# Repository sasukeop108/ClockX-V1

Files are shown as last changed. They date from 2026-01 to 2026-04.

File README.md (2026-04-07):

# ClockX-V1

This is a clock which can display time, Date etc, alarms can be set ,has games and has 4 inbuilt buttons to control them.
I decided to make this because i wake up from sleep, I cannot se the time clearly because the clock is far away from my
bed and im feeling lazy to move near the clock and see the time , So i designed ClockX which has my most favourite and usefull things at one place. First, I thought of soldering them in a zeropcb but as I was curious in learning cad and pcb designing I made a pcb and enclosure for it.

It is powered by a wemos d1 mini for proccessing all data and has 0.96 inch i2c oled display for displaying all the datas.
It has a menu with  4 options which are NTP clock, Alarm, Setting, and game. It has 1000 MaH which would power them  for some hours.
It derives time 
using the NTP protocol and inbuilt WiFi of wemos d1 mini. It has a chrome dino game in the game menu.
# Finished build
WhatsApp Image 2026-03-31 at 14 14 21
# Demo url
https://www.youtube.com/shorts/HJBQToIP37M
# cad with pcb
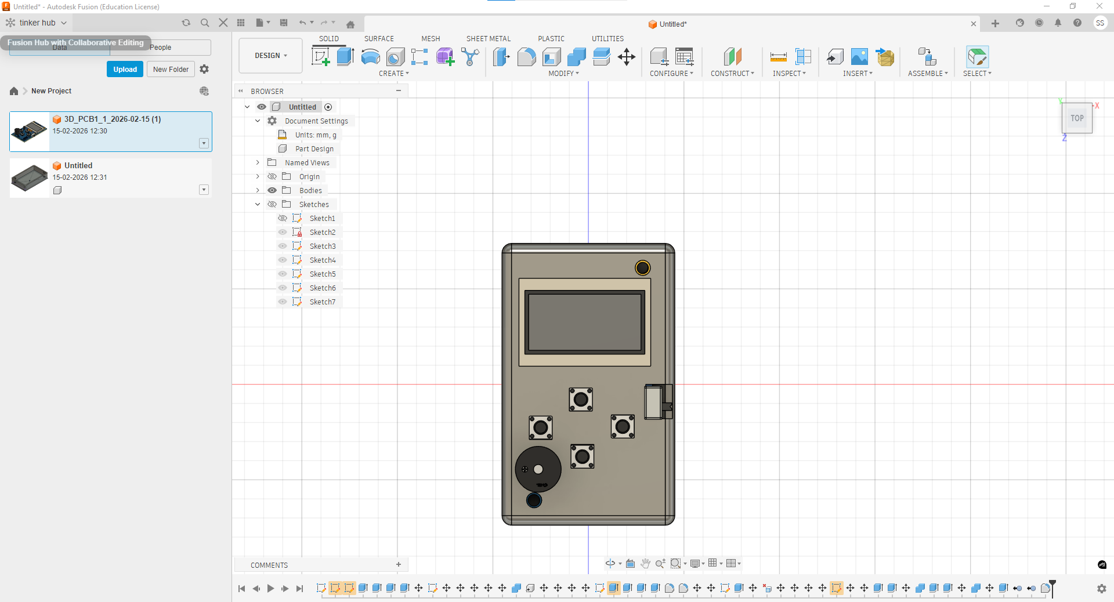
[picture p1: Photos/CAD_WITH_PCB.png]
Cad with pcb

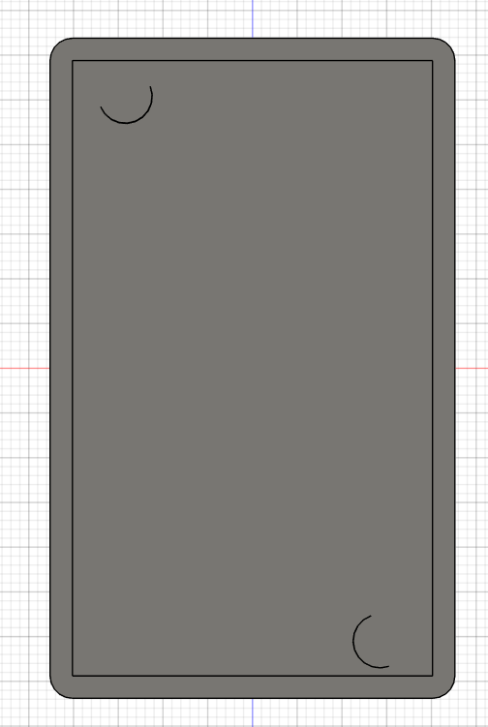
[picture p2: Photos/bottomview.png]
Schematic1


# 2D PCB & Schematic
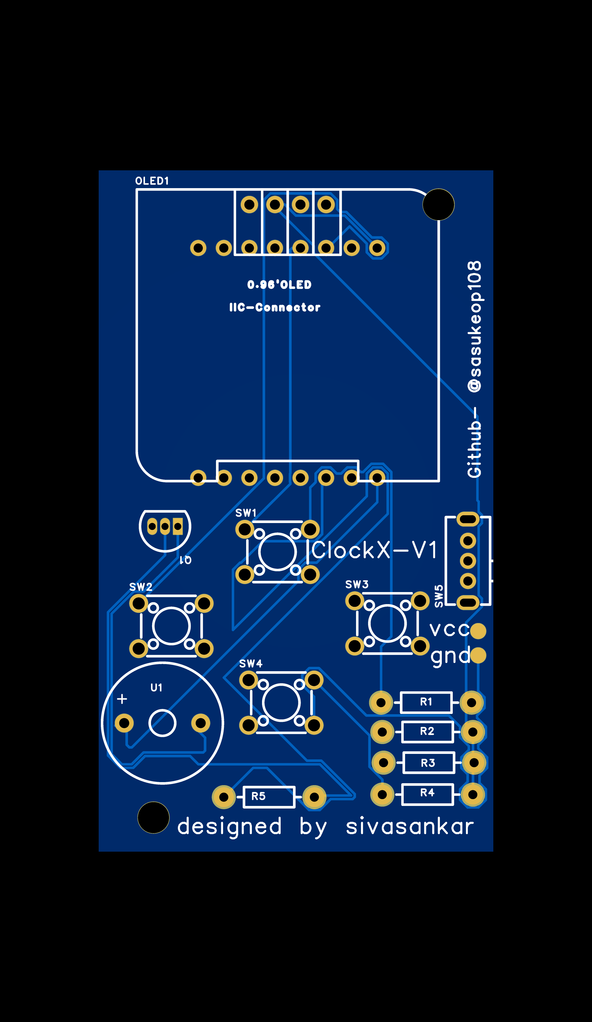
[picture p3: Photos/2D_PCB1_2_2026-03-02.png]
2d pcb

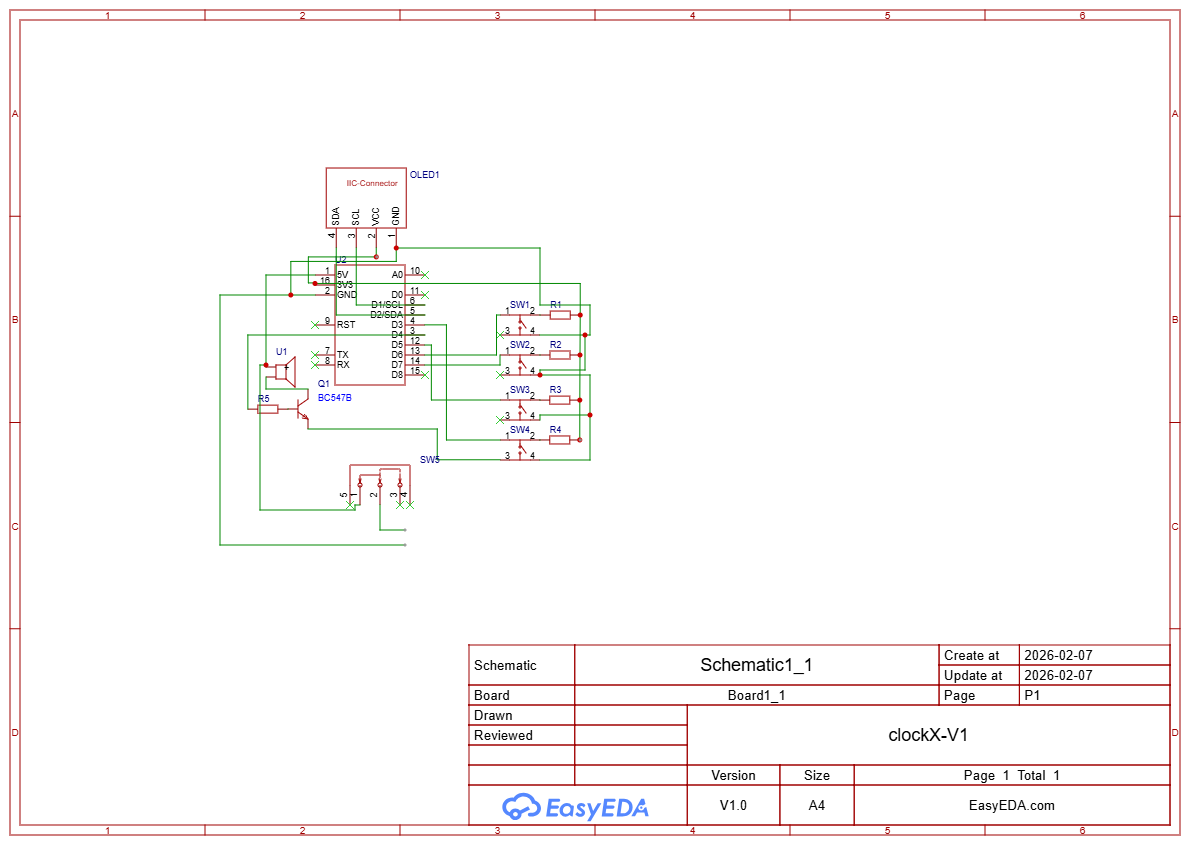
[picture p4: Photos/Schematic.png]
Schematic

# Circuit Diagram
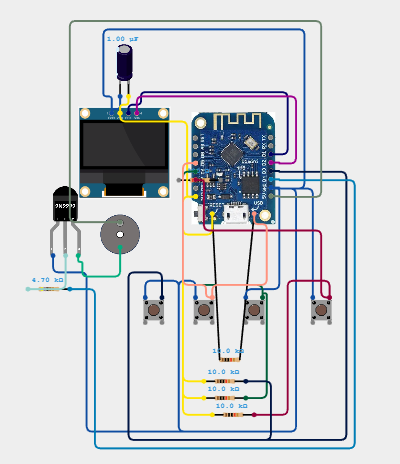
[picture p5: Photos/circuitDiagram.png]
Circuit Diagram

# BOM
# Bill of Materials

| Item | Description | Qty | Unit Price (INR) | Total (INR) | Unit Price (USD)* | Total (USD)* | Link |
| :--- | :--- | :--- | :--- | :--- | :--- | :--- | :--- |
| Microcontroller | Wemos D1 Mini | 1 | ₹699.00 | ₹699.00 | $8.42 | $8.42 | [makerbazar.in](https://makerbazar.in/products/wemos-d1-mini-iot-esp8266-based-development-board?variant=48251175600368) |
| DISPLAY | 128x64 I2C OLED Display | 1 | ₹189.00 | ₹189.00 | $2.28 | $2.28 | [makerbazar.in](https://makerbazar.in/products/0-96-inch-128x64-oled-display-module) |
| Boost Module | Step-up Converter | 1 | ~~₹65.00~~ | **Self Sourced** | ~~$0.78~~ | **Self Sourced** | **Self Sourced** |
| Buzzer | Hdp1206 Active Buzzer | 1 | ₹19.00 | ₹19.00 | $0.23 | $0.23 | [makerbazar.in](https://makerbazar.in/products/b12-hdp1206-mini-active-buzzer) |
| Button | 6x6mm Push Button | 1 | ₹20.00 | ₹20.00 | $0.24 | $0.24 | [makerbazar.in](https://makerbazar.in/products/small-push-button-switch?variant=44840000880880) |
| Battery | 800mAh LiPo Battery | 1 | ₹150.00 | ₹150.00 | $1.81 | $1.81 | [quartzcomponents.com](https://quartzcomponents.com/products/3-7v-800mah-li-po-rechargeable-battery) |
| Charger | TP4056 Charger Module | 1 | ₹16.00 | ₹16.00 | $0.19 | $0.19 | [makerbazar.in](https://makerbazar.in/products/tp4056-1a-li-ion-lithium-battery-charging-module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) |
| Resistor | 10kΩ THT Resistor (Pack of 10) | 1 | ₹5.00 | ₹5.00 | $0.06 | $0.06 | [makerbazar.in](https://makerbazar.in/products/carbon-film-resistor-dip-1-4-watt-resistance-through-hole-1k-to-99kohm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) |
| Power Switch | Slide Switch (SPDT) | 2 | ₹8.00 | ₹16.00 | $0.10 | $0.19 | [makerbazar.in](https://makerbazar.in/products/right-angle-3-pin-2-position-spdt-1p2t-pcb-panel-mini-slide-switch-l-shape-bent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) |
| Capacitor | 100µF 16V Capacitor (Pack of 10) | 1 | ₹12.00 | ₹12.00 | $0.14 | $0.14 | [makerbazar.in](https://makerbazar.in/products/electrolytic-capacitor-through-hole?variant=48721342562544) |
| Header | Female Berg Strip (40-pin) | 1 | ~~₹8.50~~ | **Self Sourced** | ~~$0.10~~ | **Self Sourced** | **Self Sourced** |
| Nut | M3*12mm nut (Pack of 10) | 1 | ₹42.00 | ₹42.00 | $0.51 | $0.51 | [quartzcomponents.com](https://quartzcomponents.com/products/m3-x-10mm-hex-allen-socket-head-ss202-screwpack-of-10) |
| Heat Insert | M3x12mm Brass Heat Set Insert Nut (10 Pcs) | 2 | ₹42.00 | ₹84.00 | $0.51 | $1.02 | [quartzcomponents.com](https://quartzcomponents.com/products/m3x12mm-brass-heat-set-threaded-round-insert-nut-10-pcs) |
| Heatshrink | Black Heatshrink (1m) | 1 | ₹7.00 | ₹7.00 | $0.08 | $0.08 | [makerbazar.in](https://makerbazar.in/products/heat-shrink?variant=44960740475120) |
| **Subtotal (Purchased Components)** | | | | **₹1259.00** | | **$15.17** | |
| **Maker Bazaar Delivery** | | | | **+₹60.00** | | **+$0.72** | |
| **Quartz Components Delivery** | | | | **+₹50.00** | | **+$0.60** | |
| **Quartz Components Tax** | | | | **+₹58.68** | | **+$0.71** | |
| **PCB Grant** | PCB Manufacturing Grant | | | **+728.61** | | **+$8** | |
| **3D Print Grant** |Shipping Grant | | | **+₹273.23** | | **+$3.00** | |
| **GRAND TOTAL** | | | | **₹2429** | | **$26.80** | |

*\*Note: USD conversions are approximate and based on an exchange rate of 1 USD = 83 INR. Actual rates may vary at the time when you see. It is approximately 27 dollar according to today's exchange rate.*

## Summary

- **Maker Bazar Purchased Items:** 9 items totaling **₹983.00** (Wemos + Display + Buzzer + Button + Charger + Resistor + Switch + Capacitor + Heatshrink)
- **Quartz Components Items:** Battery + Nut + 2×Heat Insert = **₹276.00**
- **Self Sourced Items:** Boost Module (₹65) + Header (₹8.50) = **₹73.50**
- **Delivery & Tax:** Maker Bazaar Delivery (₹60) + Quartz Delivery (₹50) + Quartz Tax (₹58.68) = **₹168.68**
- **Grants:** PCB Grant (₹728.61) + 3D Print Grant (₹273.23) = **₹1002**
- **Grand Total:** **2429 INR** (approximately **$27 USD**)

## Self Sourced Items (Not Purchased)
- Boost Module (Step-up Converter) - ₹65.00
- Header (Female Berg Strip 40-pin) - ₹8.50

# Key Features
* Game high scores are saved in EEPROM

* Alarms will still continue even when the game is being used

* All the alarm's are saved in EEPROM

* Live and accurate time with no mistake

* The use of a specific button can be changed by coding

  # Libraries Required

  * Wire.h
  * u8g2lib.h
  * ESP8266WiFi.h
  * EEPROM.h
  * NTPClient.h
  * WiFiUDP.h

 **Reference and inspiration**

 https://youtu.be/3gI2dTkNN_A?si=NC1nUjIlxpC8zosO
    
**Project url**- https://blueprint.hackclub.com/projects/9123

**Installation**

First, Solder the wemos d1 mini after thar Solder other Components and flash the firmware.Now Solder the battery wires in Vcc and gnd pad. Next, Insert the heart inserts into case usin a soldering iron and keep that pcb in place,keep the lod above it and tighten the screws.Finally, You're ready to go with ClockX!

**Estimated battery life**

4.5 to 6 hours~

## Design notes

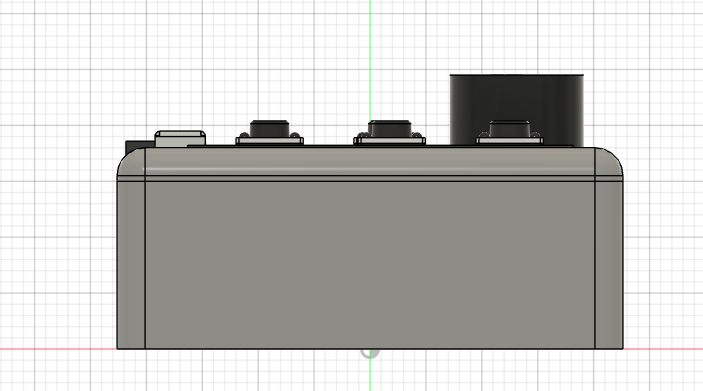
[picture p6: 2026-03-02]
Photos/backview.png

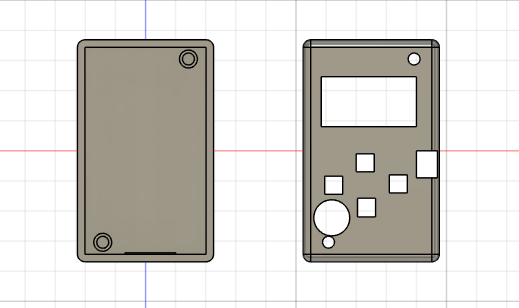
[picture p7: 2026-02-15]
Photos/CAD_WITHOUT_PCB.png

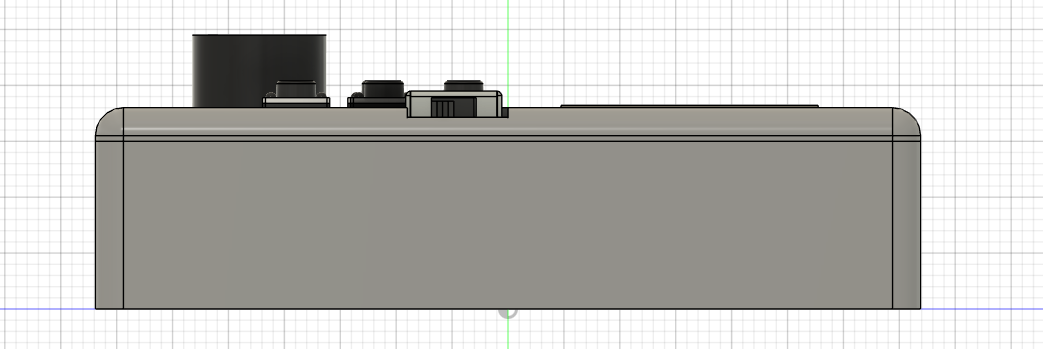
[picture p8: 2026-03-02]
Photos/rightview.png

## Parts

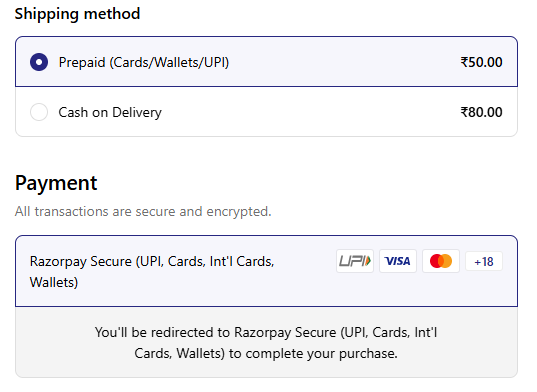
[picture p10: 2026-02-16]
BOM/QuartzComponents_Delivery.png

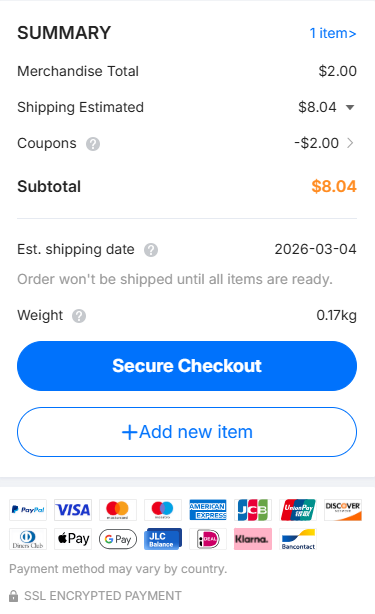
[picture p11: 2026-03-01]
BOM/jlcpcb6.png

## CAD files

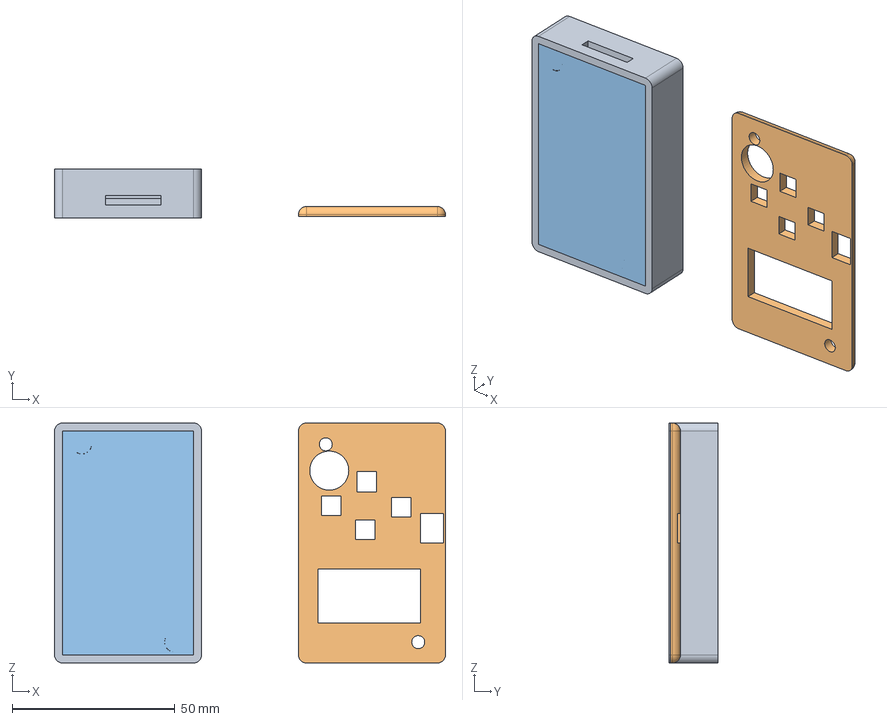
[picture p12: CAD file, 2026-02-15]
CAD/ClockX-V1_NO_PCB (1).step
120.2 x 15.0 x 73.8 mm

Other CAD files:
CAD/CaseBottom.f3d
CAD/TopCase.f3d

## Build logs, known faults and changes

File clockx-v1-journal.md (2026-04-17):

<!--
  This journal is auto generated by Hack Club Blueprint.
-->

# 1/7/2026 6 PM - Designed OLED UI  

_Time spent: 1.0h_  

**DAY** 1

Today, I designed a good user interface for my OLED display using lopaka. It turned out  very well. I also include options to use Clock and Game seperately. It took me 45 mins but UI was worth for spending the time.

# 1/7/2026 9 PM - Designed circuit diagram  

_Time spent: 1.0h_  

**DAY 1** circuitDiagram
Today, I spent 1 hour and to choose components and complete my circuit diagram. I added all the components needed for the project and connected them. Finally i checked all the wiring and ensured that there were no mistakes in the wiring part.

# 1/8/2026 - Started coding for the proect  

_Time spent: 1.3h_  

**DAY 2**

Today, I started coding for my project's NTP clock part. Learnt basics ofu8g2, NTPClient and wrote this code. I had many syntax errors in my code. After compiling, Found 6 syntax errors which i fixed immediately.

My code had some declaration and software errors too which i also fixed and compiled again. This time, There were no errors and NTP CLOCK part was good to go. I completed 1 part out of the 3 parts of my project which are NTP clock, Game and ALARM.

**TIME SPENT** : Around 1 hour & 30 mins  

# 1/9/2026 - Completed coding the project  

_Time spent: 3.4h_  

**DAY 3**

Today, I modified the code which i wrote yesterday. The code which i wrote yesterday was too 
basic, So today i modified all the basic code to advanced which was pretty cool at first. After completing the code, I realized that the button management was too complex.

Due to the complexity of button handling i added a setting in menu which will display all the button handling. Also, The previous code only had clock, But today i added all the parts (games,settings,alarm). Like always had many errors which i fixed.

**time spent**: 3.45 Hour.  

# 1/11/2026 - Created BOM and changed circuit diagram  

_Time spent: 2.0h_  

**DAY 4**

Today, There were several changes in my project. I changed the micro controller from esp8266 to wemos d1 mini because of its very small size. Because oh this i also was forced to create a new circuit diagram. i did it.

Also, I created the BOM of my project using excel. This might be the final journal of my project because my project is in final phase which is prototyping.

**TIME SPENT**: 2 hours  

# 2/15/2026 - Drew schematic, Routed pcb and created a 3d enclosure   

_Time spent: 3.1h_  

CAD_WITH_PCB

**CAD_WITHOUT_PCB**
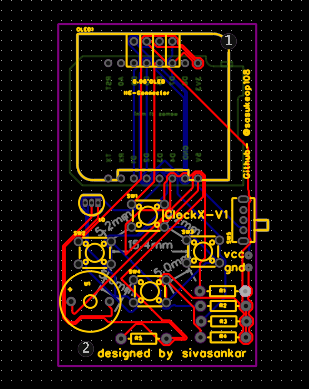
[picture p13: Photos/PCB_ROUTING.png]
PCB_ROUTING
Schematic
**DAY 5**

Today, I started by creating a schematic for my pcb in easy eda and routed the pcb again and again until I felt it was fine. It took very long perfecting it and was satisfied of the routing the pcb finally.

After that, I started creating a enclosure for the pcb. It was also same like routing pcb. It took long to perfect it but not very much comparing to the pcb routing. Finally completed 3 works and I was satisfied very much of my work.

**TIME SPENT- 3 HOUR 10 MINUTES**  

# 2/24/2026 - Update in prices  

_Time spent: 0.1h_  

Screenshot_20260224_163838_Chrome

Today when I checked the prices of pcbs in jlcpcb, The prices have been reduced due to end of chinese new year,so now the Grant I require has been changed to 29.34 dollar

# 3/1/2026 - Change in the Grant needed  

_Time spent: 0.1h_  

Screenshot_20260301_140226_Chrome AS the shipping cost for 3d Print is bargained and reduced to 3 dollar from 6 dollar, The Grant which I want has been updated to 24 dollars. SO I Have updated BOM  

# 3/14/2026 - Uploaded Firmware and tested  

_Time spent: 3.0h_  

Today, I received all of the components needed for my project except the pcb. So i uploaded the firmware to the wemos d1 mini. After that i used the pcb schematic to form a circuit using breadboard and breadboard wires. There were some problems too after fixing them it worked well and i have tested it with the lipo battery too.WhatsApp Image 2026-03-14 at 22.12.18
WhatsApp Image 2026-03-14 at 22.12.19

# 3/18/2026 - Soldered all parts in pcb  

_Time spent: 3.0h_  

Today, i received my pcb from jlcpcb so i started soldering all the components onto the pcb. First, It was working fine but after i soldered the buzzer,Transistor and its resistor the esp suddenly crashed. I was panicked for a minute because the esp didnt reset and screen didnt work. I debugged for approx 1 hour and i finally found out that the buzzer was pulling the boot pin high during boot. After i removed those components it started working fine.WhatsApp Image 2026-03-18 at 21.09.08

# 3/31/2026 - Completed the project  

_Time spent: 2.2h_  

WhatsApp Image 2026-03-31 at 14.14.21
WhatsApp Image 2026-03-31 at 14.14.22
Today, I got my 3d parts so i inserted the heat inserts. After that i soldered tp4056 and boost module, secured them in place. I also done some other small changes in my code for improving the project. Finally now it is completed and this might be my last journal.

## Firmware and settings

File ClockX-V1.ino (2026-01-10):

//by Sivasankar github repository: https://github.com/sasukeop108/ClockX-V1

#include <U8g2lib.h>
#include <NTPClient.h>
#include <WiFiUdp.h>
#include <ESP8266WiFi.h>
#include <Wire.h>
#include <EEPROM.h>

//BUTTON PIN ASSIGNMENTS
#define b1 12  // D6 - GPIO12 (Menu navigation) Add 10KΩ resistor to 3.3V!
#define b2 13  // D7 - GPIO13 (Select/Jump) Add 10KΩ resistor to 3.3V!
#define b3 14  // D5 - GPIO14 (Increase/Restart) Add 10KΩ resistor to 3.3V!
#define b4 0   // D3 - GPIO0 (Decrease/Back)  Add 10KΩ resistor to 3.3V!

// Buzzer Pin
#define BUZZER_PIN 2  // D4 - GPIO2 connect this pin to base of 2n222a transistor with a 1k resistor,connect emitter with gnd and connect buzzer gnd to collector and positive of buzzer to 5v

int sen = 1; // Start at Clock (1=Clock, 2=Game, 3=Alarm, 4=Settings)

// OLED Display
U8G2_SSD1306_128X64_NONAME_F_HW_I2C u8g2(U8G2_R0, U8X8_PIN_NONE);

// NTP Client
WiFiUDP ntpUDP;
NTPClient timeClient(ntpUDP, "pool.ntp.org", 19800);

// Icons
static const unsigned char image_calendar_bits[] U8X8_PROGMEM = {0x90,0x04,0x6e,0x3b,0xff,0x7f,0xff,0x7f,0x01,0x40,0x61,0x5b,0x61,0x5b,0x01,0x40,0x6d,0x5b,0x6d,0x5b,0x01,0x40,0x6d,0x43,0x6d,0x43,0x01,0x40,0xfe,0x3f,0x00,0x00};
static const unsigned char image_clock_alarm_bits[] U8X8_PROGMEM = {0x9e,0x3c,0xcd,0x59,0xb7,0x76,0x0b,0x68,0x05,0x50,0x82,0x20,0x82,0x20,0x81,0x40,0x83,0x60,0x41,0x40,0x22,0x20,0x12,0x20,0x04,0x10,0x08,0x08,0xb4,0x16,0xc2,0x21};
static const unsigned char image_wifi_full_bits[] U8X8_PROGMEM = {0x80,0x0f,0x00,0xe0,0x3f,0x00,0x78,0xf0,0x00,0x9c,0xcf,0x01,0xee,0xbf,0x03,0xf7,0x78,0x07,0x3a,0xe7,0x02,0xdc,0xdf,0x01,0xe8,0xb8,0x00,0x70,0x77,0x00,0xa0,0x2f,0x00,0xc0,0x1d,0x00,0x80,0x0a,0x00,0x00,0x07,0x00,0x00,0x02,0x00,0x00,0x00,0x00};
static const unsigned char image_settings_bits[] U8X8_PROGMEM = {
  0x00,0x00,0x0e,0x00,0x1f,0x00,0x3b,0x80,0x71,0xc0,0xe0,0xe0,0xc0,0x70,0x80,0x38,
  0x00,0x1c,0x00,0x0e,0x00,0x07,0x80,0x03,0xc0,0x01,0xe0,0x00,0x70,0x00,0x38,0x00,
  0x1c,0x00,0x0e,0x00,0x07,0x80,0x03,0xc0,0x01,0xe0,0x00,0x70,0x00,0x38,0x00,0x1c,
  0x00,0x0e,0x00,0x07,0x80,0x03,0xc0,0x01,0xe0,0x00,0x70,0x00,0x38,0x00,0x00,0x00
};

// BUZZER FUNCTIONS
void playTone(int frequency, int duration) {
  if (frequency == 0) {
    noTone(BUZZER_PIN);
    return;
  }
  tone(BUZZER_PIN, frequency, duration);
}

void playPulsingAlarm() {
  static unsigned long lastToneTime = 0;
  static int pulseState = 0;
  unsigned long currentTime = millis();
  
  if (currentTime - lastToneTime > 100) {
    switch(pulseState) {
      case 0: playTone(1000, 80); break;
      case 1: playTone(1200, 80); break;
      case 2: playTone(1400, 80); break;
      case 3: playTone(0, 0); break;
    }
    pulseState = (pulseState + 1) % 4;
    lastToneTime = currentTime;
  }
}

void playJumpSound() { playTone(800, 50); delay(10); playTone(600, 40); }
void playGameOverSound() { playTone(300, 200); delay(100); playTone(200, 300); delay(150); playTone(150, 400); }
void playButtonClick() { playTone(500, 30); }
void playAlarmSetSound() { playTone(800, 100); delay(50); playTone(1000, 100); }
void stopAllSounds() { noTone(BUZZER_PIN); }

// EEPROM
#define EEPROM_SIZE 512
#define HIGH_SCORE_ADDR 0

struct Alarm {
  byte hour;
  byte minute;
  bool enabled;
};

#define MAX_ALARMS 3
Alarm alarms[MAX_ALARMS];

// GAME VARIABLES
#define GROUND_Y 54
#define GRAVITY 0.5
#define JUMP_FORCE -9.0
#define INITIAL_SPEED 3

// Dino Sprites
static const unsigned char dino_run1[] U8X8_PROGMEM = {
  0x00,0x00,0x00,0x00,0x00,0x00,0x00,0x00,0x00,0x00,0x00,0x00,0x00,0x00,0x00,0x00,
  0x00,0x00,0x00,0x00,0x00,0x00,0x00,0x00,0x00,0x00,0x03,0xe0,0x03,0xf0,0x07,0xf0,
  0x07,0xf0,0x07,0xf0,0x07,0xf0,0x07,0xe0,0x07,0xf0,0x07,0xf0,0x07,0xf8,0x0f,0xf8,
  0x0f,0xf8,0x0f,0xf0,0x07,0xf0,0x07,0xf0,0x03,0xe0,0x00,0x00,0x00,0x00,0x00,0x00
};

static const unsigned char cactus_small[] U8X8_PROGMEM = {
  0x00,0x00,0x01,0x80,0x01,0x80,0x01,0x80,0x01,0x80,0x01,0x80,0x01,0x80,0x01,0x80,
  0x01,0x80,0x01,0x80,0x01,0x80,0x01,0x80,0x01,0x80,0x01,0x80,0x01,0x80,0x01,0x80,
  0x01,0x80,0x01,0x80,0x01,0x80,0x01,0x80,0x01,0x80,0x01,0x80,0x01,0x80,0x01,0x80,
  0x01,0x80,0x01,0x80,0x01,0x80,0x01,0x80,0x01,0x80,0x01,0x80,0x01,0x80,0x00,0x00
};

struct Dino {
  float x = 10;
  float y = GROUND_Y - 16;
  float velocity = 0;
  bool jumping = false;
  int frame = 0;
} dino;

struct Obstacle {
  float x;
  bool active = false;
};

Obstacle obstacles[2];
bool gameOver = false;
unsigned long score = 0;
unsigned long highScore = 0;
float gameSpeed = INITIAL_SPEED;

// ALARM STATE
int alarmMenuState = 0;
int currentAlarm = 0;
int editingField = 0;
bool alarmTriggered = false;

//WIFI 
const char* ssid = "Sivasankarjio 5g";
const char* password = "siva2012";

String WeekDays[7] = {"Sun", "Mon", "Tue", "Wed", "Thu", "Fri", "Sat"};
String Months[13] = {"", "Jan", "Feb", "Mar", "Apr", "May", "Jun", "Jul", "Aug","Sep", "Oct", "Nov", "Dec"};

//SETUP 
void setup() {
  Serial.begin(115200);
  
  // Initialize buttons
  pinMode(b1, INPUT);  // D6
  pinMode(b2, INPUT);  // D7
  pinMode(b3, INPUT);  // D5
  pinMode(b4, INPUT);  // D3 
  
  // Initialize buzzer
  pinMode(BUZZER_PIN, OUTPUT);
  digitalWrite(BUZZER_PIN, LOW);
  
  u8g2.begin();
  u8g2.clearBuffer();
  u8g2.setFont(u8g2_font_t0_18b_tr);
  u8g2.drawStr(5, 28, "CONNECTING TO");
  u8g2.drawStr(46, 44, "WiFi");
  u8g2.sendBuffer();
  
  // Initialize EEPROM
  EEPROM.begin(EEPROM_SIZE);
  loadHighScore();
  loadAlarms();
  
  WiFi.begin(ssid, password);
  while (WiFi.status() != WL_CONNECTED) {
    delay(500);
  }
  
  timeClient.begin();
  
  // Startup sound
  playButtonClick();
  delay(200);
  playButtonClick();
}

// EEPROM FUNCTIONS
void loadHighScore() {
  EEPROM.get(HIGH_SCORE_ADDR, highScore);
  if (highScore > 100000) highScore = 0;
}

void saveHighScore() {
  EEPROM.put(HIGH_SCORE_ADDR, highScore);
  EEPROM.commit();
}

void loadAlarms() {
  for(int i = 0; i < MAX_ALARMS; i++) {
    int addr = 10 + (i * sizeof(Alarm));
    EEPROM.get(addr, alarms[i]);
  }
}

void saveAlarms() {
  for(int i = 0; i < MAX_ALARMS; i++) {
    int addr = 10 + (i * sizeof(Alarm));
    EEPROM.put(addr, alarms[i]);
  }
  EEPROM.commit();
  playAlarmSetSound();
}

// MAIN LOOP
void loop() {
  // Show main menu (NOW WITH 4 OPTIONS)
  u8g2.clearBuffer();
  u8g2.setFont(u8g2_font_t0_12b_tr);
  u8g2.drawStr(22, 10, "WiFi NTP CLOCK");
  u8g2.drawStr(52, 25, "GAME");
  u8g2.drawStr(49, 40, "ALARM");
  u8g2.drawStr(44, 55, "SETTINGS");
  
  // Highlight current selection
  if (sen == 1) u8g2.drawFrame(19, 1, 92, 16);      // Clock
  else if (sen == 2) u8g2.drawFrame(47, 18, 33, 14); // Game
  else if (sen == 3) u8g2.drawFrame(43, 33, 40, 14); // Alarm
  else if (sen == 4) u8g2.drawFrame(39, 48, 55, 14); // Settings
  
  u8g2.sendBuffer();
  
  // Button handling
  if (digitalRead(b1) == LOW) {  // D6 - Menu navigation
    delay(200);
    playButtonClick();
    sen++;
    if (sen > 4) sen = 1;
  }
  
  if (digitalRead(b2) == LOW) {  // D7 - Select
    delay(200);
    playButtonClick();
    
    if (sen == 1) {
      showClock();
    } 
    else if (sen == 2) {
      playDinoGame();
    }
    else if (sen == 3) {
      showAlarmSystem();
    }
    else if (sen == 4) {
      showSettings();
    }
  }
  
  delay(50);
}

// CLOCK FUNCTION 
void showClock() {
  unsigned long lastUpdate = 0;
  
  while (digitalRead(b1) == HIGH) {
    if(millis() - lastUpdate > 1000) {
      timeClient.update();
      time_t epochTime = timeClient.getEpochTime();
      struct tm *ptm = localtime(&epochTime);
      
      int mday = ptm->tm_mday;
      int mon = ptm->tm_mon + 1;
      int year = ptm->tm_year + 1900;
      String date = (mday < 10 ? "0" : "") + String(mday) + " " + Months[mon] + " " + String(year % 100);
      
      int hour24 = timeClient.getHours();
      int mins = timeClient.getMinutes();
      int secs = timeClient.getSeconds();
      String period = (hour24 < 12) ? "AM" : "PM";
      int h12 = (hour24 % 12 == 0) ? 12 : hour24 % 12;
      String timeDisplay = (h12 < 10 ? "0" : "") + String(h12) + ":" + (mins < 10 ? "0" : "") + String(mins);
      
      checkAlarmTrigger();
      
      u8g2.clearBuffer();
      
      // Header
      u8g2.setFont(u8g2_font_4x6_tr);
      u8g2.drawStr(1, 6, "WiFi NTP CLOCK");
      u8g2.drawLine(2, 7, 127, 7);
      
      // Time
      u8g2.setFont(u8g2_font_t0_22b_tr);
      u8g2.drawStr(28, 42, timeDisplay.c_str());
      
      // Seconds
      u8g2.setFont(u8g2_font_t0_14b_tr);
      u8g2.setCursor(85, 42);
      u8g2.print(secs < 10 ? "0" : "");
      u8g2.print(secs);
      
      // Day and AM/PM
      u8g2.setFont(u8g2_font_t0_11b_tr);
      u8g2.drawStr(88, 23, WeekDays[timeClient.getDay()].c_str());
      u8g2.drawStr(22, 22, period.c_str());
      
      // Date
      u8g2.setFont(u8g2_font_t0_11b_tr);
      u8g2.setCursor(0, 56);
      u8g2.print(date);
      
      // Icons
      u8g2.drawXBMP(108, 12, 19, 16, image_wifi_full_bits);
      u8g2.drawXBMP(3, 10, 15, 16, image_clock_alarm_bits);
      u8g2.drawXBMP(104, 45, 15, 16, image_calendar_bits);
      
      u8g2.sendBuffer();
      lastUpdate = millis();
    }
    
    if(alarmTriggered) {
      showAlarmTriggered();
    }
    
    delay(10);
  }
  delay(200);
}

void checkAlarmTrigger() {
  if(alarmTriggered) return;
  
  int currentHour = timeClient.getHours();
  int currentMinute = timeClient.getMinutes();
  
  for(int i = 0; i < MAX_ALARMS; i++) {
    if(alarms[i].enabled && 
       alarms[i].hour == currentHour && 
       alarms[i].minute == currentMinute) {
      alarmTriggered = true;
      break;
    }
  }
}

void showAlarmTriggered() {
  static bool blink = false;
  static unsigned long lastBlink = 0;
  
  u8g2.clearBuffer();
  
  if(millis() - lastBlink > 300) {
    blink = !blink;
    lastBlink = millis();
  }
  
  if(blink) {
    u8g2.setDrawColor(0);
    u8g2.drawBox(0, 0, 128, 64);
    u8g2.setDrawColor(1);
  }
  
  u8g2.setFont(u8g2_font_timR24_tr);
  u8g2.drawStr(20, 35, "ALARM!");
  
  u8g2.setFont(u8g2_font_t0_11b_tr);
  u8g2.drawStr(40, 55, "Press b2 to stop");
  
  u8g2.sendBuffer();
  
  playPulsingAlarm();
  
  if(digitalRead(b2) == LOW) {
    alarmTriggered = false;
    stopAllSounds();
    delay(200);
  }
}

//DINO GAME
void playDinoGame() {
  resetGame();
  
  u8g2.clearBuffer();
  u8g2.setFont(u8g2_font_t0_16b_tr);
  u8g2.drawStr(35, 20, "DINO");
  u8g2.drawStr(25, 40, "PRESS B2");
  u8g2.drawStr(20, 55, "TO JUMP");
  u8g2.sendBuffer();
  delay(1500);
  
  unsigned long lastFrame = 0;
  unsigned long lastObstacle = millis();
  
  while(digitalRead(b1) == HIGH && !gameOver) {
    unsigned long now = millis();
    
    if(now - lastFrame >= 16) {
      updateGame();
      drawGame();
      lastFrame = now;
    }
    
    if(digitalRead(b2) == LOW) {
      if(!dino.jumping) {
        dino.velocity = JUMP_FORCE;
        dino.jumping = true;
        playJumpSound();
      }
      delay(100);
    }
    
    if(gameOver && digitalRead(b3) == LOW) {
      resetGame();
      playButtonClick();
      delay(200);
    }
    
    if(now - lastObstacle > random(1000, 2500)) {
      spawnObstacle();
      lastObstacle = now;
    }
    
    delay(1);
  }
  
  if(gameOver) {
    showGameOver();
    delay(2000);
  }
}

void updateGame() {
  if(dino.jumping) {
    dino.y += dino.velocity;
    dino.velocity += GRAVITY;
    
    if(dino.y >= GROUND_Y - 16) {
      dino.y = GROUND_Y - 16;
      dino.jumping = false;
      dino.velocity = 0;
    }
  }
  
  dino.frame = (dino.frame + 1) % 20;
  
  for(int i = 0; i < 2; i++) {
    if(obstacles[i].active) {
      obstacles[i].x -= gameSpeed;
      
      if(obstacles[i].x < -10) {
        obstacles[i].active = false;
        score += 1;
      }
    }
  }
  
  for(int i = 0; i < 2; i++) {
    if(obstacles[i].active) {
      if(dino.x + 16 > obstacles[i].x &&
         dino.x < obstacles[i].x + 8 &&
         dino.y + 16 > GROUND_Y - 16) {
        gameOver = true;
        playGameOverSound();
        if(score > highScore) {
          highScore = score;
          saveHighScore();
        }
        return;
      }
    }
  }
}

void drawGame() {
  u8g2.clearBuffer();
  
  u8g2.drawLine(0, GROUND_Y, 128, GROUND_Y);
  
  if(dino.frame < 10) {
    u8g2.drawXBMP(dino.x, dino.y, 16, 16, dino_run1);
  } else {
    u8g2.drawXBMP(dino.x, dino.y, 16, 16, dino_run1);
  }
  
  for(int i = 0; i < 2; i++) {
    if(obstacles[i].active) {
      u8g2.drawXBMP(obstacles[i].x, GROUND_Y - 16, 8, 16, cactus_small);
    }
  }
  
  char scoreStr[20];
  u8g2.setFont(u8g2_font_5x7_tr);
  sprintf(scoreStr, "SCORE: %lu", score);
  u8g2.drawStr(80, 10, scoreStr);
  
  sprintf(scoreStr, "HIGH: %lu", highScore);
  u8g2.drawStr(80, 20, scoreStr);
  
  u8g2.sendBuffer();
}

void spawnObstacle() {
  for(int i = 0; i < 2; i++) {
    if(!obstacles[i].active) {
      obstacles[i].x = 128;
      obstacles[i].active = true;
      break;
    }
  }
}

void resetGame() {
  dino.x = 10;
  dino.y = GROUND_Y - 16;
  dino.velocity = 0;
  dino.jumping = false;
  dino.frame = 0;
  
  for(int i = 0; i < 2; i++) {
    obstacles[i].active = false;
  }
  
  score = 0;
  gameSpeed = INITIAL_SPEED;
  gameOver = false;
}

void showGameOver() {
  u8g2.clearBuffer();
  
  u8g2.setFont(u8g2_font_t0_16b_tr);
  u8g2.drawStr(30, 20, "GAME OVER");
  
  u8g2.setFont(u8g2_font_t0_12b_tr);
  char scoreStr[30];
  sprintf(scoreStr, "Score: %lu", score);
  u8g2.drawStr(40, 35, scoreStr);
  
  sprintf(scoreStr, "High: %lu", highScore);
  u8g2.drawStr(40, 50, scoreStr);
  
  u8g2.drawStr(10, 63, "b3=Restart  b1=Exit");
  
  u8g2.sendBuffer();
}

//ALARM SYSTEM
void showAlarmSystem() {
  alarmMenuState = 0;
  currentAlarm = 0;
  
  while(digitalRead(b1) == HIGH) {
    
    if(alarmMenuState == 0) {
      u8g2.clearBuffer();
      u8g2.setFont(u8g2_font_t0_16b_tr);
      u8g2.drawStr(40, 15, "ALARMS");
      
      u8g2.setFont(u8g2_font_6x10_tr);
      
      for(int i = 0; i < MAX_ALARMS; i++) {
        char alarmStr[20];
        sprintf(alarmStr, "%d: %02d:%02d %s", 
                i+1, 
                alarms[i].hour, 
                alarms[i].minute,
                alarms[i].enabled ? "ON" : "OFF");
        
        int yPos = 30 + (i * 12);
        
        if(i == currentAlarm) {
          u8g2.drawBox(0, yPos-10, 128, 12);
          u8g2.setDrawColor(0);
        }
        
        u8g2.drawStr(5, yPos, alarmStr);
        
        if(i == currentAlarm) {
          u8g2.setDrawColor(1);
        }
      }
      
      u8g2.drawStr(5, 58, "b2:Edit  b3:Next  b4:Prev");
      
      u8g2.sendBuffer();
      
      if(digitalRead(b2) == LOW) {
        delay(200);
        playButtonClick();
        alarmMenuState = 1;
        editingField = 0;
      }
      
      if(digitalRead(b3) == LOW) {
        delay(200);
        playButtonClick();
        currentAlarm = (currentAlarm + 1) % MAX_ALARMS;
      }
      
      if(digitalRead(b4) == LOW) {
        delay(200);
        playButtonClick();
        currentAlarm = (currentAlarm - 1 + MAX_ALARMS) % MAX_ALARMS;
      }
    }
    else {
      static bool blink = false;
      static unsigned long lastBlink = 0;
      
      if(millis() - lastBlink > 500) {
        blink = !blink;
        lastBlink = millis();
      }
      
      u8g2.clearBuffer();
      u8g2.setFont(u8g2_font_t0_16b_tr);
      char title[20];
      sprintf(title, "ALARM %d", currentAlarm + 1);
      u8g2.drawStr(30, 15, title);
      
      u8g2.setFont(u8g2_font_timR24_tr);
      char timeStr[6];
      sprintf(timeStr, "%02d:%02d", alarms[currentAlarm].hour, alarms[currentAlarm].minute);
      u8g2.drawStr(26, 45, timeStr);
      
      if(blink) {
        if(editingField == 0) {
          u8g2.drawBox(26, 46, 40, 3);
        } else if(editingField == 1) {
          u8g2.drawBox(70, 46, 40, 3);
        }
      }
      
      u8g2.setFont(u8g2_font_6x10_tr);
      char statusStr[20];
      sprintf(statusStr, "Status: %s", alarms[currentAlarm].enabled ? "ENABLED" : "DISABLED");
      
      if(editingField == 2 && blink) {
        u8g2.drawBox(45, 48, 60, 10);
        u8g2.setDrawColor(0);
      }
      u8g2.drawStr(45, 58, statusStr);
      u8g2.setDrawColor(1);
      
      u8g2.setFont(u8g2_font_4x6_tr);
      u8g2.drawStr(5, 63, "b3/b4:Adjust  b2:Save");
      
      u8g2.sendBuffer();
      
      if(digitalRead(b2) == LOW) {
        delay(200);
        playButtonClick();
        saveAlarms();
        alarmMenuState = 0;
      }
      
      if(digitalRead(b3) == LOW) {
        delay(200);
        playButtonClick();
        adjustAlarmValue(1);
      }
      
      if(digitalRead(b4) == LOW) {
        delay(200);
        playButtonClick();
        adjustAlarmValue(-1);
      }
    }
    
    delay(10);
  }
  
  delay(200);
}

void adjustAlarmValue(int delta) {
  switch(editingField) {
    case 0: alarms[currentAlarm].hour = (alarms[currentAlarm].hour + delta + 24) % 24; break;
    case 1: alarms[currentAlarm].minute = (alarms[currentAlarm].minute + delta + 60) % 60; break;
    case 2: alarms[currentAlarm].enabled = !alarms[currentAlarm].enabled; break;
  }
  editingField = (editingField + 1) % 3;
}

// SETTINGS/HELP MENU 
void showSettings() {

  int settingsPage = 0;
  
  while(digitalRead(b1) == HIGH) {
    
    if(settingsPage == 0) {
      // BUTTON GUIDE PAGE - Optimized layout
      u8g2.clearBuffer();
      
      u8g2.setFont(u8g2_font_t0_16b_tr);
      u8g2.drawStr(30, 12, "BUTTON GUIDE");
      u8g2.drawLine(2, 15, 126, 15);
      
      // Use 4x6 font for everything
      u8g2.setFont(u8g2_font_4x6_tr);
      
      // Row 1
      u8g2.drawStr(5, 25, "b1(D6): Menu Nav/Exit");
      
      // Row 2
      u8g2.drawStr(5, 33, "b2(D7): Select/Jump");
      
      // Row 3
      u8g2.drawStr(5, 41, "b3(D5): Increase/Next");
      
      // Row 4
      u8g2.drawStr(5, 49, "b4(D3): Decrease/Prev");
      
      // Row 5 - Game specific
      u8g2.drawStr(5, 57, "Game: b2=Jump b3=Restart");
      
      // Footer
      u8g2.drawStr(5, 63, "b3:Next Page  b1:Exit");
      
      u8g2.sendBuffer();
      
      if(digitalRead(b3) == LOW) {
        delay(200);
        playButtonClick();
        settingsPage = 1;
      }
    }
    else if(settingsPage == 1) {
      // SYSTEM INFO PAGE - Optimized
      u8g2.clearBuffer();
      
      u8g2.setFont(u8g2_font_t0_16b_tr);
      u8g2.drawStr(40, 12, "SYSTEM INFO");
      u8g2.drawLine(2, 15, 126, 15);
      
      u8g2.setFont(u8g2_font_4x6_tr);
      
      // Row 1: WiFi status
      u8g2.drawStr(5, 25, "WiFi:");
      u8g2.drawStr(35, 25, WiFi.status() == WL_CONNECTED ? "Connected" : "Offline");
      
      // Row 2: IP address (shortened if needed)
      u8g2.drawStr(5, 33, "IP:");
      String ipStr = WiFi.localIP().toString();
      // If IP is too long, show first part
      if(ipStr.length() > 14) {
        ipStr = ipStr.substring(0, 14);
      }
      u8g2.drawStr(35, 33, ipStr.c_str());
      
      // Row 3: High score
      u8g2.drawStr(5, 41, "High Score:");
      char hsStr[12];
      sprintf(hsStr, "%lu pts", highScore);
      u8g2.drawStr(70, 41, hsStr);
      
      // Row 4: Alarms
      u8g2.drawStr(5, 49, "Alarms:");
      int alarmsSet = 0;
      for(int i = 0; i < MAX_ALARMS; i++) {
        if(alarms[i].enabled) alarmsSet++;
      }
      char alarmStr[10];
      sprintf(alarmStr, "%d of 3 set", alarmsSet);
      u8g2.drawStr(70, 49, alarmStr);
      
      // Row 5: Memory
      u8g2.drawStr(5, 57, "Free RAM:");
      char ramStr[10];
      sprintf(ramStr, "%d bytes", ESP.getFreeHeap());
      u8g2.drawStr(70, 57, ramStr);
      
      // Footer
      u8g2.drawStr(5, 63, "b4:Prev Page  b1:Exit");
      
      u8g2.sendBuffer();
      
      if(digitalRead(b4) == LOW) {
        delay(200);
        playButtonClick();
        settingsPage = 0;
      }
    }
    
    delay(10);
  }
  

  
  delay(200);
}

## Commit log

2026-01-15 Rename BOM/Screenshot 2026-01-15 044426.png to cart.png
2026-02-15 Create GERBER
2026-02-15 Rename Annotation 2026-02-15 173847.png to PCB_ROUTING.png
2026-02-24 Update BOM.csv with revised grant amounts and totals
    [BOM.csv]
2026-02-27 Modify GRAND TOTAL and exchange rate note in BOM.csv
    Updated the GRAND TOTAL and note regarding USD conversions.
    [BOM.csv]
2026-03-01 Update note on USD conversions in BOM.csv
    [BOM.csv]
